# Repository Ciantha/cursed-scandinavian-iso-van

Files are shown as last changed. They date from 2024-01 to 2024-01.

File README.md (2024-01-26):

# cursed-scandinavian-iso-van
CC BY-NC 4.0

PCB work finished by the very kind josh-l-wang

## Images

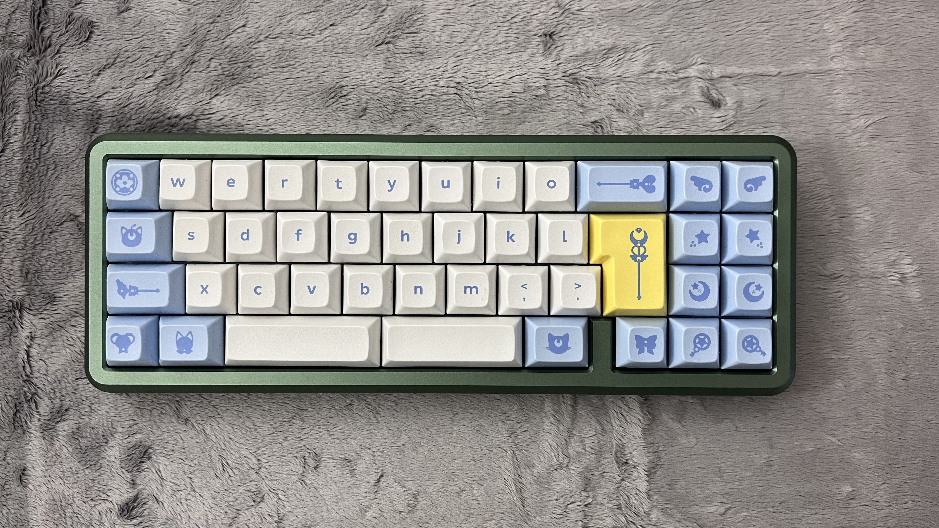
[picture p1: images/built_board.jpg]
Built board


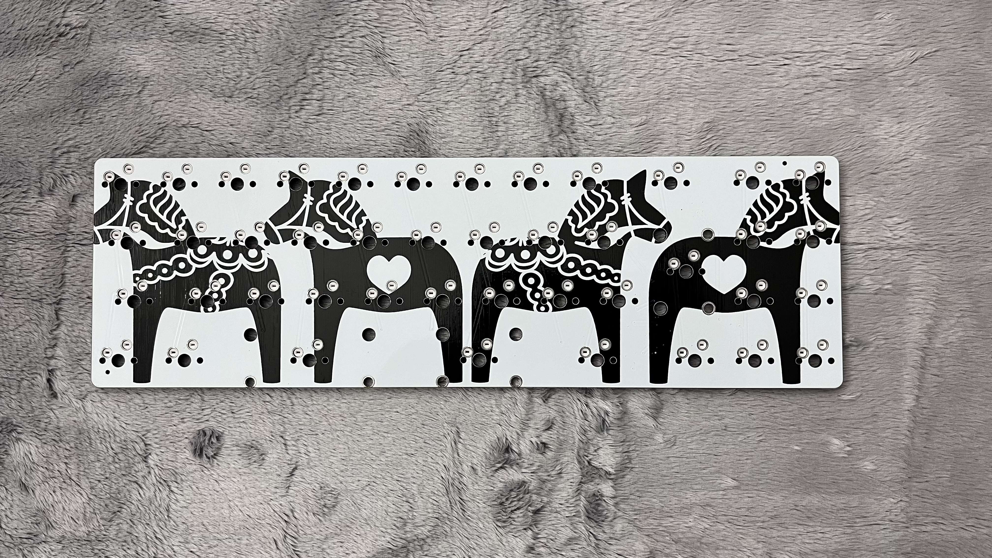
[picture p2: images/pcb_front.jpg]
PCB front


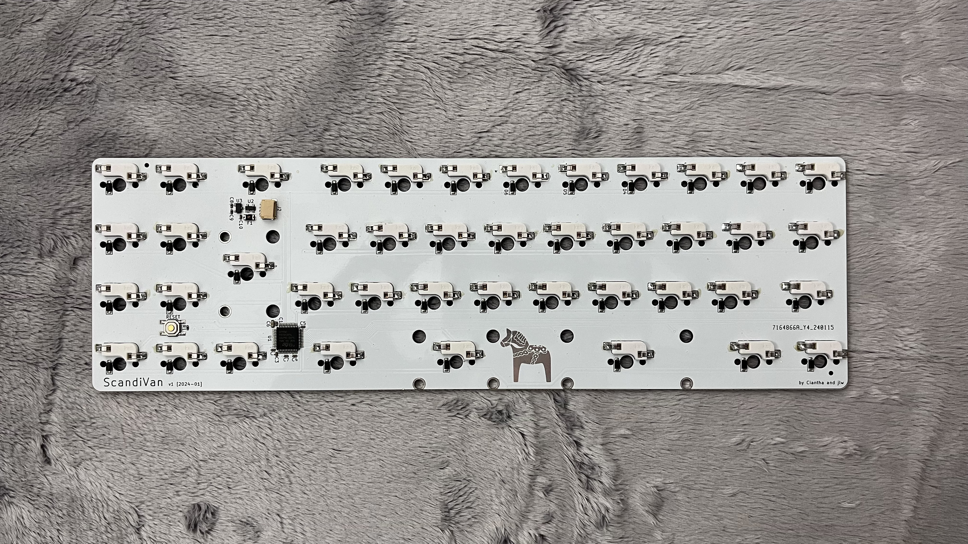
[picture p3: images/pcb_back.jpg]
PCB back


## Disclaimer
The PCB design has been tested and confirmed to work. 
However, no one associated with this project (or anyone else) is liable if you end up with a non-functional pcb. 
Order at your own risk. Support will not be provided.

## Footprints and other tools

Uses footprints from https://github.com/ebastler/marbastlib
Thanks to zykrah for the very convenient KLE plugin https://github.com/zykrah/kicad-kle-placer#installation-kicad-7

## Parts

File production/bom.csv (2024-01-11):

Designator | Footprint | Quantity | Value | LCSC Part #
C1, C10, C2, C3, C4, C5, C7 | 0402 | 7 | 100nF | C307331
C6 | 0603 | 1 | 10uF | C96446
C8, C9 | 0402 | 2 | 1uF | C52923
D1, D10, D11, D12, D13, D14, D15, D16, D17, D18, D19, D2, D20, D21, D22, D23, D24, D25, D26, D27, D28, D29, D3, D30, D31, D32, D33, D34, D35, D36, D37, D38, D39, D4, D40, D41, D42, D43, D5, D6, D7, D8, D9 | D_SOD-123 | 43 | D_Small | C81598
F1 | 1206 | 1 | ASMD1206-150 | C135341
J2 | JST_SH_SM04B-SRSS-TB_1x04-1MP_P1.00mm_Horizontal | 1 | Conn_01x04_Socket | C160404
MX1, MX11, MX12, MX14, MX15, MX16, MX17, MX18, MX19, MX2, MX20, MX21, MX22, MX23, MX24, MX26, MX27, MX28, MX29, MX3, MX30, MX31, MX32, MX33, MX34, MX35, MX36, MX38, MX39, MX4, MX41, MX42, MX43, MX5, MX6, MX7, MX8, MX9 | SW_MX_HS_1u | 38 | MX_SW_HS | C5184526
MX10 | SW_MX_HS_1.75u | 1 | MX_SW_HS | C5184526
MX13, MX37, MX40 | SW_MX_HS_1.25u | 3 | MX_SW_HS | C5184526
MX25 | SW_MX_HS_1.5u | 1 | MX_SW_HS | C5184526
R1 | 0402 | 1 | 10k | C25905
SW1 | SW_SPST_SKQG_WithoutStem | 1 | SKQGABE010 | C318884
U1 | LQFP-48-1EP_7x7mm_P0.5mm_EP3.6x3.6mm | 1 | STM32F072CBU6 | C81720
U2 | SOT-143 | 1 | PRTR5V0U2X | C2827688
U3 | SOT-23 | 1 | XC6206P332MR-Regulator_Linear | C5446

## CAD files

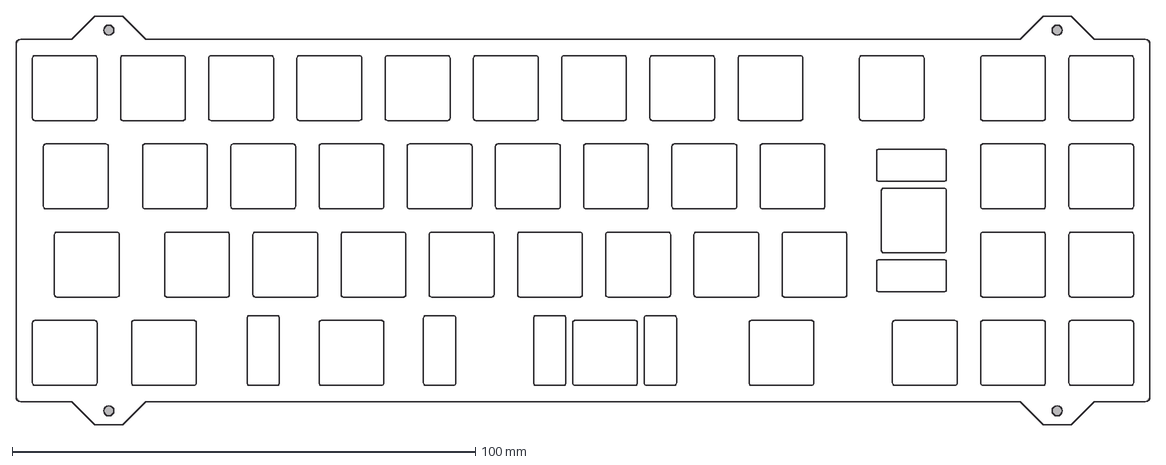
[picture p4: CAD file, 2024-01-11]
production/scandivan plate.dxf
244.9 x 88.2 mm

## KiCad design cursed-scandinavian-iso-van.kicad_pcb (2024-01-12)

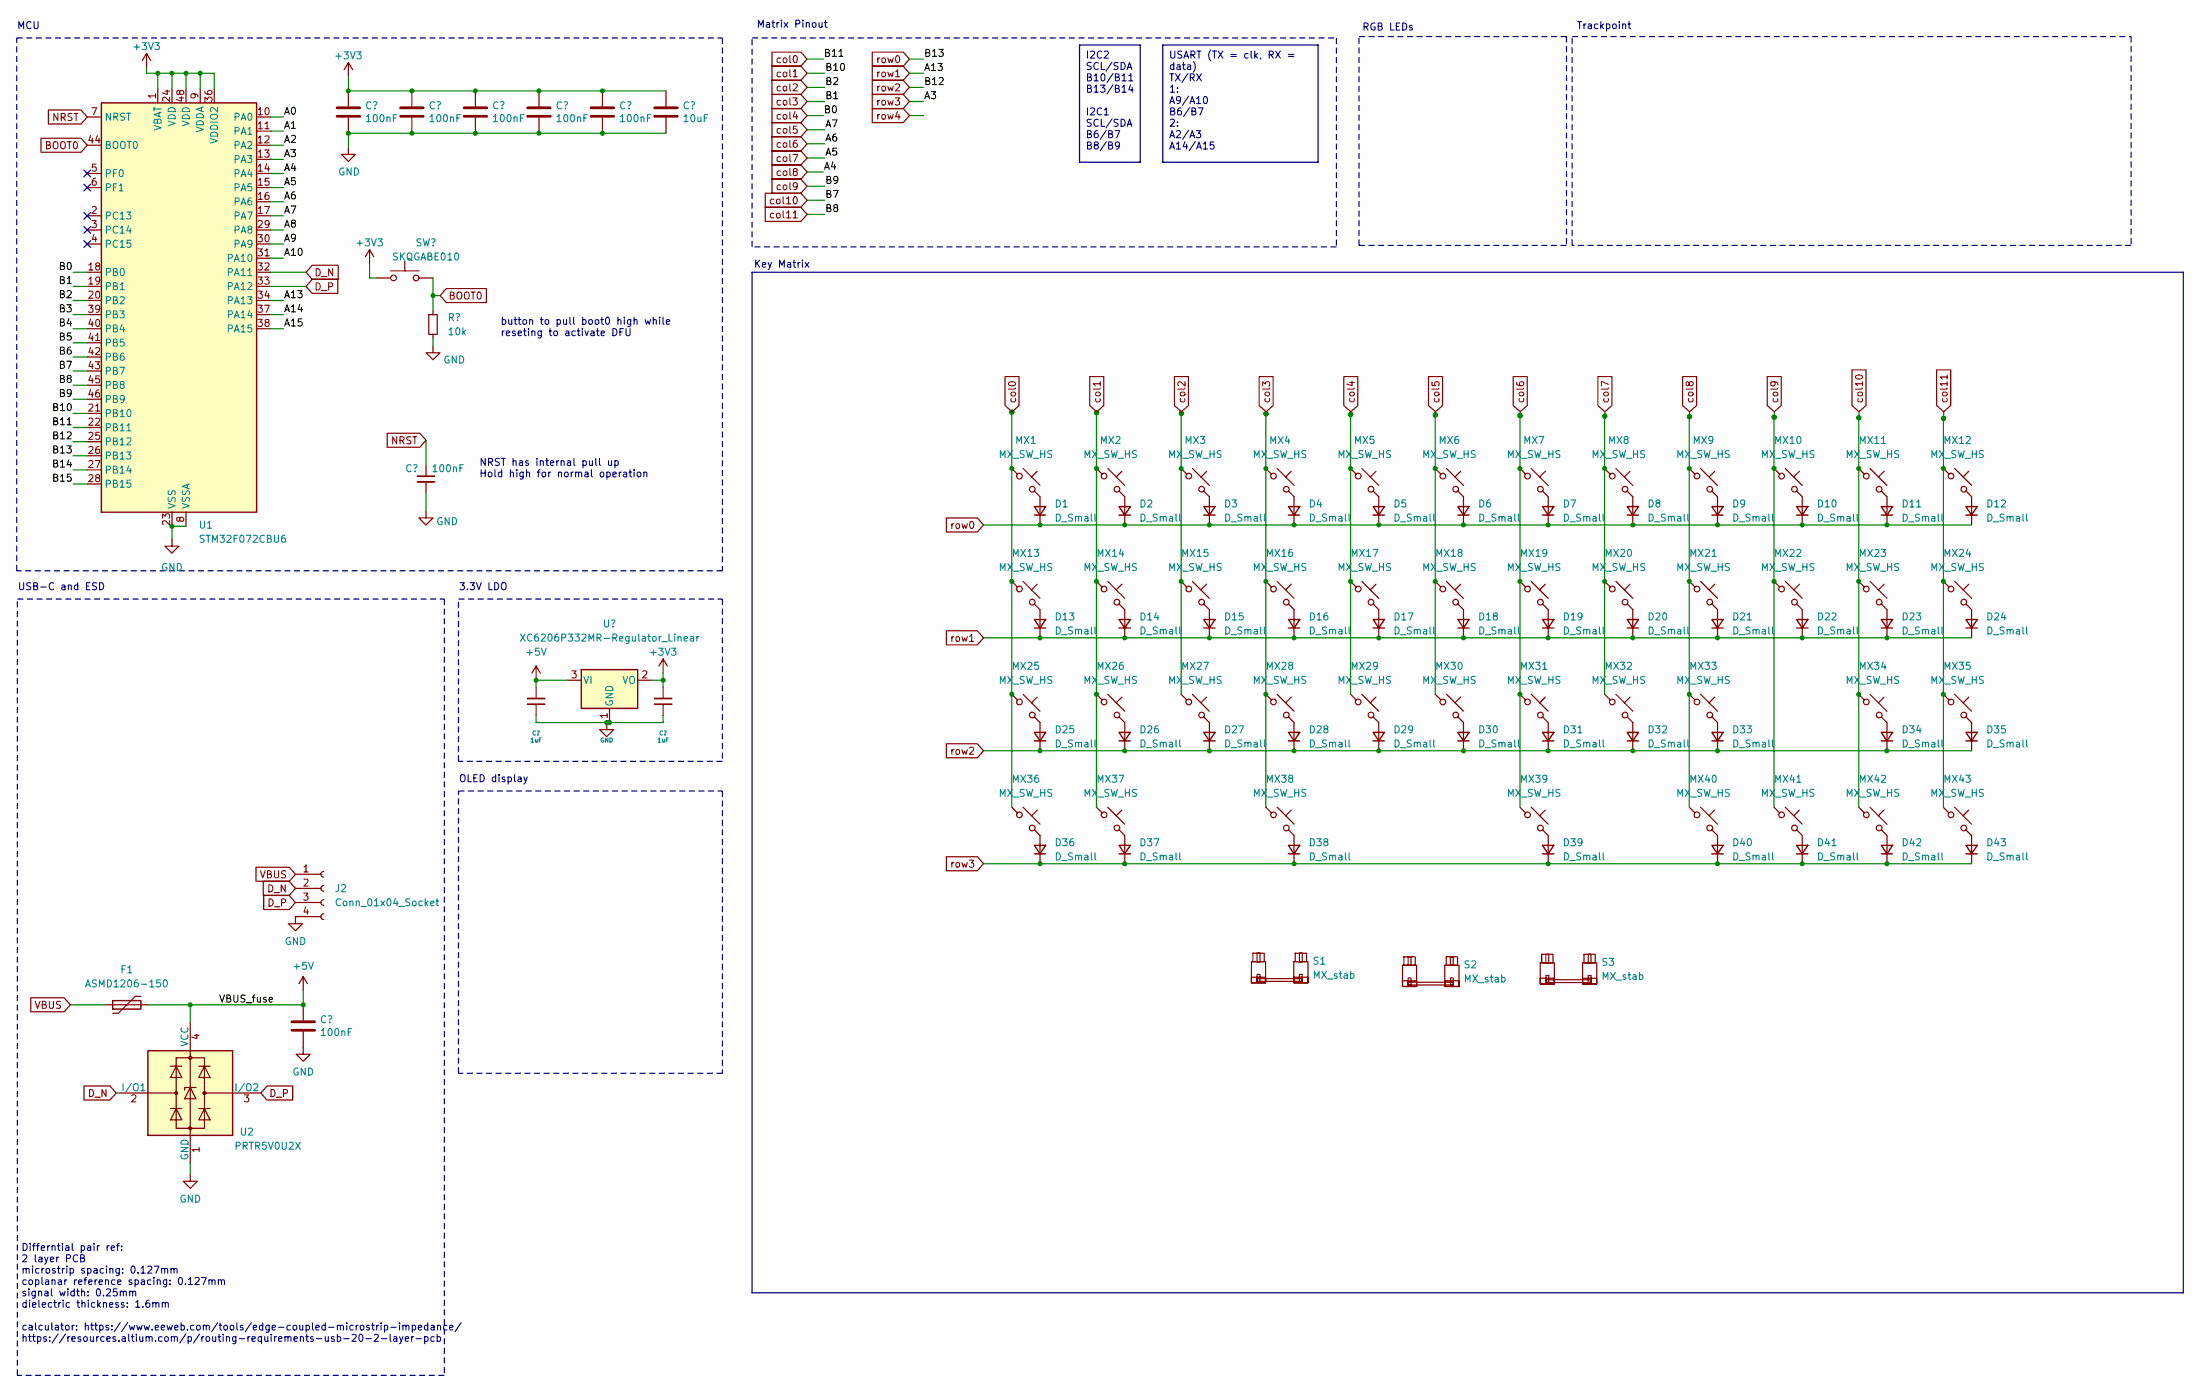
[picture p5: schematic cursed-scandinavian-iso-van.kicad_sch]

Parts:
C1, C2, C3, C4, C5, C7, C10: 100nF; C_0402_1005Metric; LCSC C307331
C6: 10uF; C_0603_1608Metric; LCSC C96446
C8, C9: 1uF; C_0402_1005Metric; LCSC C52923
D1, D2, D3, D4, D5, D6, D7, D8, D9, D10, D11, D12, D13, D14, D15, D16, D17, D18, D19, D20, D21, D22, D23, D24, D25, D26, D27, D28, D29, D30, D31, D32, D33, D34, D35, D36, D37, D38, D39, D40, D41, D42, D43: D_Small; D_SOD-123
F1: ASMD1206-150; Fuse_1206_3216Metric; LCSC C135341
J2: Conn_01x04_Socket; JST_SH_SM04B-SRSS-TB_1x04-1MP_P1.00mm_Horizontal
MX1, MX2, MX3, MX4, MX5, MX6, MX7, MX8, MX9, MX11, MX12, MX14, MX15, MX16, MX17, MX18, MX19, MX20, MX21, MX22, MX23, MX24, MX26, MX27, MX28, MX29, MX30, MX31, MX32, MX33, MX34, MX35, MX36, MX38, MX39, MX41, MX42, MX43: MX_SW_HS; SW_MX_HS_1u
MX10: MX_SW_HS; SW_MX_HS_1.75u
MX13, MX37, MX40: MX_SW_HS; SW_MX_HS_1.25u
MX25: MX_SW_HS; SW_MX_HS_1.5u
R1: 10k; R_0402_1005Metric; LCSC C25905
S1: MX_stab; STAB_MX_P_3u
S2: MX_stab; STAB_MX_P_2.75u
S3: MX_stab; STAB_MX_P_ISO-ROT
SW1: SKQGABE010; SW_SPST_SKQG_WithoutStem; LCSC C318884
U1: STM32F072CBU6; LQFP-48-1EP_7x7mm_P0.5mm_EP3.6x3.6mm; JlcRotOffset 90
U2: PRTR5V0U2X; SOT-143; LCSC C2827688
U3: XC6206P332MR-Regulator_Linear; SOT-23; LCSC C5446

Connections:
+3V3: C1.1, C2.1, C3.1, C4.1, C5.1, C6.1, C9.2, SW1.1, U1.1 (VBAT), U1.9 (VDDA), U1.24 (VDD), U1.36 (VDDIO2), U1.48 (VDD), U3.2 (VO)
+5V: C8.2, C10.1, F1.2, U2.4 (VCC), U3.3 (VI)
/A0: U1.10 (PA0)
/A1: U1.11 (PA1)
/A2: U1.12 (PA2)
/A8: U1.29 (PA8)
/A9: U1.30 (PA9)
/A10: U1.31 (PA10)
/A14: U1.37 (PA14)
/A15: U1.38 (PA15)
/B3: U1.39 (PB3)
/B4: U1.40 (PB4)
/B5: U1.41 (PB5)
/B6: U1.42 (PB6)
/B14: U1.27 (PB14)
/B15: U1.28 (PB15)
BOOT0: R1.1, SW1.2, U1.44 (BOOT0)
D_N: J2.2, U1.32 (PA11), U2.2 (I/O1)
D_P: J2.3, U1.33 (PA12), U2.3 (I/O2)
GND: C1.2, C2.2, C3.2, C4.2, C5.2, C6.2, C7.2, C8.1, C9.1, C10.2, J2.4, R1.2, U1.8 (VSSA), U1.23 (VSS), U1.35 (VSS), U1.47 (VSS), U1.49 (VSS), U2.1 (GND), U3.1 (GND)
NRST: C7.1, U1.7 (NRST)
unnamed: D1.2 (A), MX1.2
unnamed: D2.2 (A), MX2.2
unnamed: D3.2 (A), MX3.2
unnamed: D4.2 (A), MX4.2
unnamed: D5.2 (A), MX5.2
unnamed: D6.2 (A), MX6.2
unnamed: D7.2 (A), MX7.2
unnamed: D8.2 (A), MX8.2
unnamed: D9.2 (A), MX9.2
unnamed: D10.2 (A), MX10.2
unnamed: D11.2 (A), MX11.2
unnamed: D12.2 (A), MX12.2
unnamed: D13.2 (A), MX13.2
unnamed: D14.2 (A), MX14.2
unnamed: D15.2 (A), MX15.2
unnamed: D16.2 (A), MX16.2
unnamed: D17.2 (A), MX17.2
unnamed: D18.2 (A), MX18.2
unnamed: D19.2 (A), MX19.2
unnamed: D20.2 (A), MX20.2
unnamed: D21.2 (A), MX21.2
unnamed: D22.2 (A), MX22.2
unnamed: D23.2 (A), MX23.2
unnamed: D24.2 (A), MX24.2
unnamed: D25.2 (A), MX25.2
unnamed: D26.2 (A), MX26.2
unnamed: D27.2 (A), MX27.2
unnamed: D28.2 (A), MX28.2
unnamed: D29.2 (A), MX29.2
unnamed: D30.2 (A), MX30.2
unnamed: D31.2 (A), MX31.2
unnamed: D32.2 (A), MX32.2
unnamed 53: D33.2 (A), MX33.2; also elsewhere on the board
unnamed: D34.2 (A), MX34.2
unnamed: D35.2 (A), MX35.2
unnamed: D36.2 (A), MX36.2
unnamed: D37.2 (A), MX37.2
unnamed: D38.2 (A), MX38.2
unnamed: D39.2 (A), MX39.2
unnamed: D40.2 (A), MX40.2
unnamed: D41.2 (A), MX41.2
unnamed: D42.2 (A), MX42.2
unnamed: D43.2 (A), MX43.2
VBUS: F1.1, J2.1
col0: MX1.1, MX13.1, MX25.1, MX36.1, U1.22 (PB11)
col1: MX2.1, MX14.1, MX26.1, MX37.1, U1.21 (PB10)
col2: MX3.1, MX15.1, MX27.1, U1.20 (PB2)
col3: MX4.1, MX16.1, MX28.1, MX38.1, U1.19 (PB1)
col4: MX5.1, MX17.1, MX29.1, U1.18 (PB0)
col5: MX6.1, MX18.1, MX30.1, U1.17 (PA7)
col6: MX7.1, MX19.1, MX31.1, MX39.1, U1.16 (PA6)
col7: MX8.1, MX20.1, MX32.1, U1.15 (PA5)
col8: MX9.1, MX21.1, MX33.1, MX40.1, U1.14 (PA4); also elsewhere on the board
col9: MX10.1, MX22.1, MX41.1, U1.46 (PB9)
col10: MX11.1, MX23.1, MX34.1, MX42.1, U1.43 (PB7)
col11: MX12.1, MX24.1, MX35.1, MX43.1, U1.45 (PB8)
row0: D1.1 (K), D2.1 (K), D3.1 (K), D4.1 (K), D5.1 (K), D6.1 (K), D7.1 (K), D8.1 (K), D9.1 (K), D10.1 (K), D11.1 (K), D12.1 (K), U1.26 (PB13)
row1: D13.1 (K), D14.1 (K), D15.1 (K), D16.1 (K), D17.1 (K), D18.1 (K), D19.1 (K), D20.1 (K), D21.1 (K), D22.1 (K), D23.1 (K), D24.1 (K), U1.34 (PA13)
row2: D25.1 (K), D26.1 (K), D27.1 (K), D28.1 (K), D29.1 (K), D30.1 (K), D31.1 (K), D32.1 (K), D33.1 (K), D34.1 (K), D35.1 (K), U1.25 (PB12)
row3: D36.1 (K), D37.1 (K), D38.1 (K), D39.1 (K), D40.1 (K), D41.1 (K), D42.1 (K), D43.1 (K), U1.13 (PA3)

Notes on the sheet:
USART (TX = clk, RX = data) TX/RX 1: A9/A10 B6/B7 2: A2/A3 A14/A15
I2C2 SCL/SDA B10/B11 B13/B14 I2C1 SCL/SDA B6/B7 B8/B9
button to pull boot0 high while reseting to activate DFU
Matrix Pinout
MCU
RGB LEDs
Trackpoint
3.3V LDO
USB-C and ESD
OLED display
NRST has internal pull up Hold high for normal operation
Differntial pair ref: 2 layer PCB microstrip spacing: 0.127mm coplanar reference spacing: 0.127mm signal width: 0.25mm dielectric thickness: 1.6mm calculator: https://www.eeweb.com/tools/edge-coupled-microstrip-impedance/ https://resources.altium.com/p/routing-requirements-usb-20-2-layer-pcb
Key Matrix

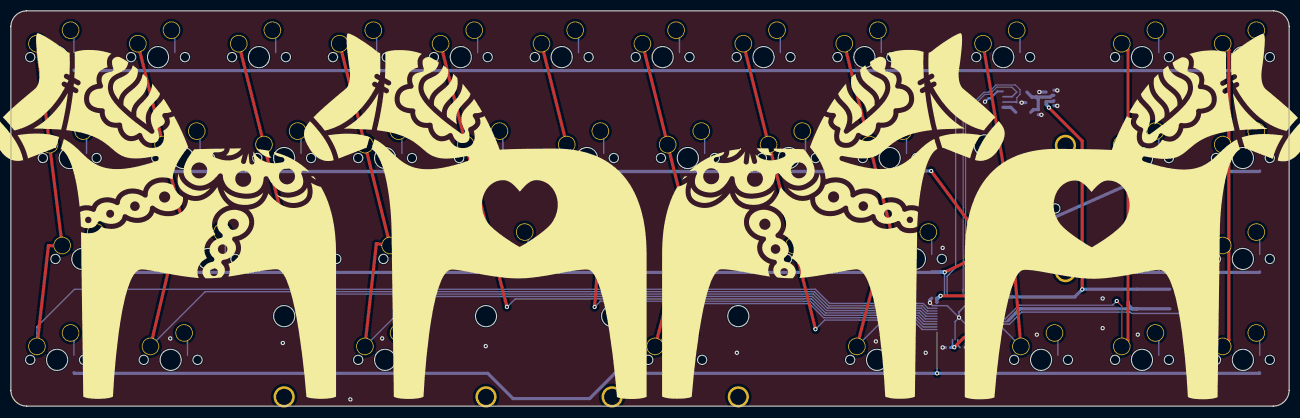
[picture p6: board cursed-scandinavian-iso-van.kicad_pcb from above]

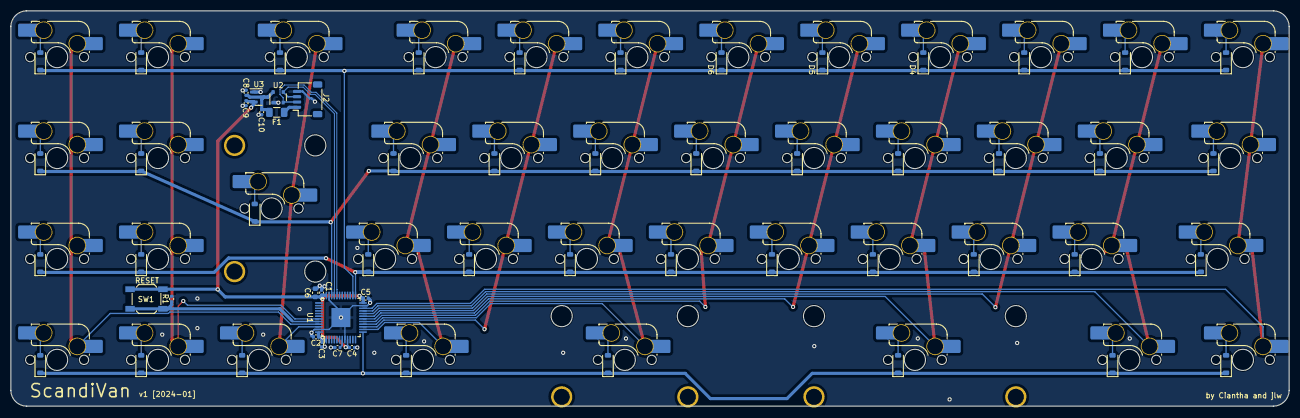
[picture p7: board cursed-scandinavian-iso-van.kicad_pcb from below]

Board: 2 copper layers, 241.3 x 74.6 mm, 106 parts (103 on the bottom side), 67 nets.

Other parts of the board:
locked: MX_SW_HS; SW_MX_HS_1u

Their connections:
unnamed 53: locked.2; also elsewhere on the board
col8: locked.1; also elsewhere on the board

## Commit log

2023-07-08 created kicad project
    [cursed-scandinavian-iso-van.kicad_pcb, cursed-scandinavian-iso-van.kicad_sch]
2023-07-08 first pass of schematic
    [cursed-scandinavian-iso-van.kicad_sch]
2023-07-08 begun routing
    [cursed-scandinavian-iso-van.kicad_pcb, cursed-scandinavian-iso-van.kicad_sch]
2023-07-08 rerouted everything again
    [cursed-scandinavian-iso-van.kicad_pcb]
2023-07-08 maybe all the columns
    [cursed-scandinavian-iso-van.kicad_pcb, cursed-scandinavian-iso-van.kicad_sch]
2023-07-08 only silk and edge complaints
    [cursed-scandinavian-iso-van.kicad_pcb, cursed-scandinavian-iso-van.kicad_sch]
2023-07-09 hid silkscreen for diodes
    [cursed-scandinavian-iso-van.kicad_pcb]
2023-07-09 generated gerbers
    [cursed-scandinavian-iso-van-B_Cu.gbr, cursed-scandinavian-iso-van-B_Mask.gbr, cursed-scandinavian-iso-van-B_Paste.gbr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]
2023-07-09 and one more save
    [cursed-scandinavian-iso-van.kicad_pcb]
2023-07-13 second attempt
    [cursed-scandinavian-iso-van.kicad_pcb, cursed-scandinavian-iso-van.kicad_sch]
2023-07-21 tuned data line
    [cursed-scandinavian-iso-van.kicad_pcb]
2024-01-11 finish PCB in STM32
    [bom.csv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]
2024-01-11 add plates
    fit original MB44 cases
    [scandivan plate.dxf, scandivan plate.kicad_pcb]
2024-01-12 updated PCB
    [cursed-scandinavian-iso-van.kicad_pcb, cursed-scandinavian-iso-van.kicad_sch]
